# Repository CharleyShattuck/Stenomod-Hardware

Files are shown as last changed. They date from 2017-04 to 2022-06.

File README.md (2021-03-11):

# Stenomod-Hardware

TinyMod4 is the current keyboard. TinyModsplit is a prototype split version of TinyMod.

formerly:
In addition to the left hand module for stenomod15, the one with the split S- into two keys, we now have the three boards currently being used in stenomods. Stenomod16 is the new hinge model. Tiny-stenomod is the new TinyMod model.

KiCad footprints used here were found at https://github.com/ruiqimao/keyboard-pcb-guide

License for Gateron.pretty is not known as it was modified from the file "CHERRY\_PCB\_100H.kicad\_mod", obtained at  https://github.com/stormbard/Keyboard.pretty  which had no expressed license.

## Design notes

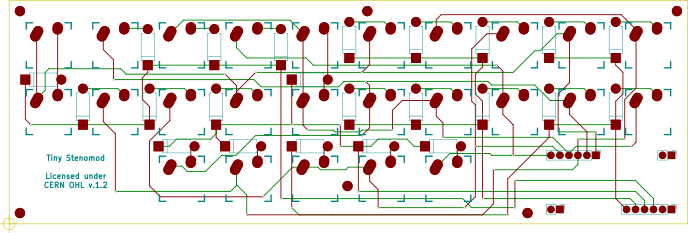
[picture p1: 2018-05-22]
Tiny-stenomod/Tiny-stenomod-brd.png

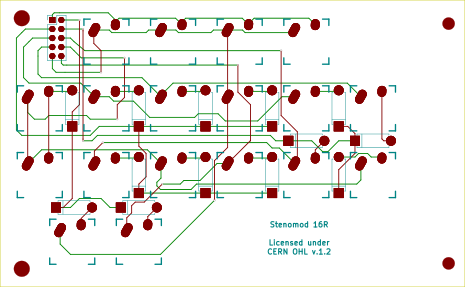
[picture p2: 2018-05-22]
Stenomod/Stenomod_Right/stenomod-16R-brd.png

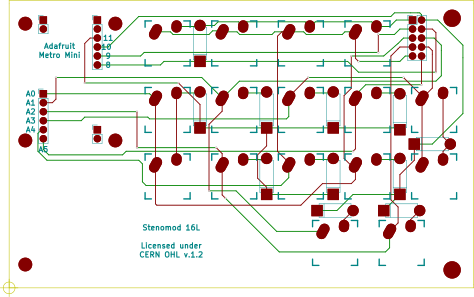
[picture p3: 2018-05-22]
Stenomod/Stenomod_Left/stenomod-16L-brd.png

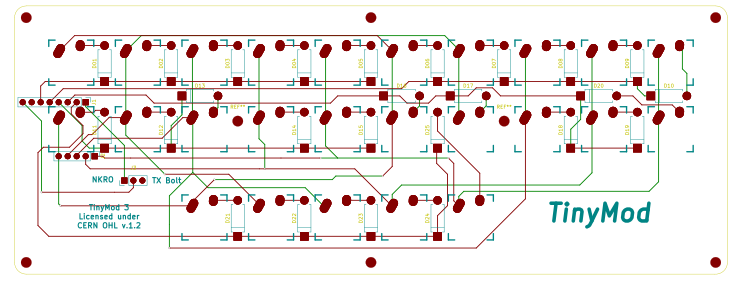
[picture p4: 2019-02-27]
TinyMod/TinyMod3/TinyMod3-brd.png

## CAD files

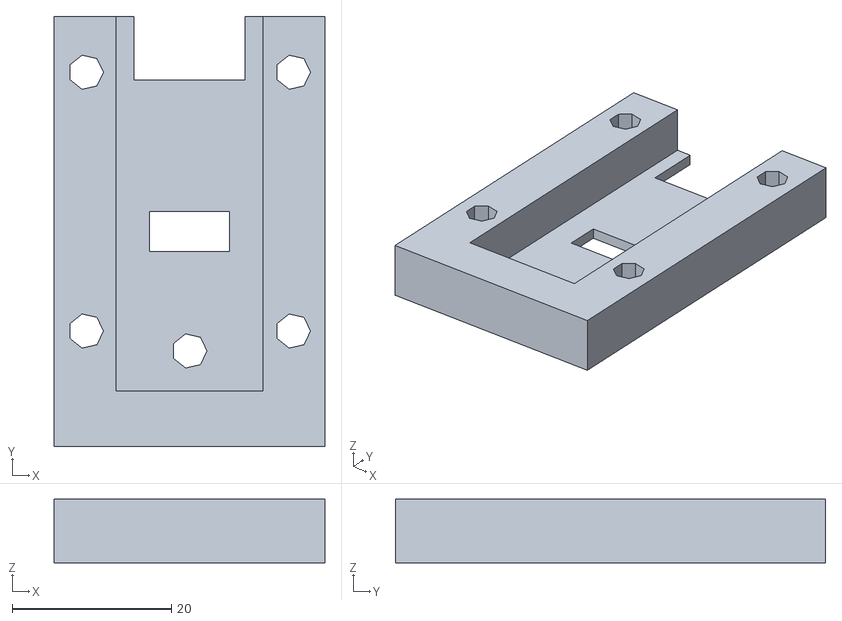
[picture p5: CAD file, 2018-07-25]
Stenomod/Stenomod_Hinge/stenomod-hinge.stl
34.0 x 54.0 x 8.00

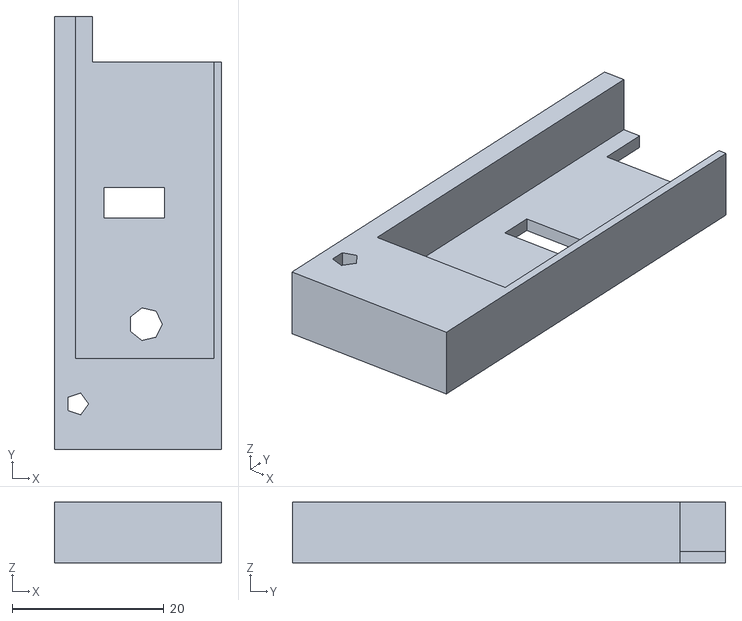
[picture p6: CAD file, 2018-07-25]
TinyMod/TinyModCover/TinyMod.stl
22.0 x 57.0 x 8.00

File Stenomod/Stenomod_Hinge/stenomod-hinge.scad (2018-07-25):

module base(){
    translate([-17, -27, 0]){
        cube([34, 54, 8]);
    }
};

module window(){
    translate([-5, -2.5, 0]){
        cube([10, 5, 10]);
    }
};

module notch(){
    translate([-7, 19, 0]){
        cube([14, 8, 10]);
    }
};

module hole(){
    cylinder(10, 2.2, 2.2, 0);
};

module reset(){
    translate([0, -15, 0]){
        hole();
    }
};

module screws(){
    translate([-13, 20, 0]){
        hole();
    }
    translate([13, 20, 0]){
        hole();
    }
    translate([-13, -12.5, 0]){
        hole();
    }
    translate([13, -12.5, 0]){
        hole();
    }
};

module middle(){
    translate([-9.25, -20, 1.5]){
        cube([18.5, 48, 10]);
    }
};

module top(){
    difference(){
        base();
        window();
        notch();
        reset();
        screws();
        middle();
    }
}

top();

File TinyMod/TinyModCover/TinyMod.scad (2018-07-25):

module base(){
    translate([-12, -27, 0]){
        cube([21, 57, 8]);
    }
};

module window(){
    translate([-5.5, 3.5, 0]){
        cube([8, 4, 10]);
    }
};

module notch(){
    translate([-7, 24, 0]){
        cube([16, 8, 10]);
    }
};

module hole1(){
    translate([0, 5, 0]){
        cylinder(10, 2.2, 2.2, 0);
    }
};

module hole2(){
    translate([0, 5, 0]){
        cylinder(10, 1.5, 1.5, 0);
    }
};

module reset(){
    translate([0, -15.5, 0]){
        hole1();
    }
};

module screws(){
    translate([-9, -26, 0]){
        hole2();
    }
};

module middle(){
    translate([-9.25, -15, 1.5]){
        cube([18.5, 48, 10]);
    }
};

module lip(){
    translate([9, -27, 0]){
        cube([1, 51, 8]);
    }
}

module top(){
    lip();
    difference(){
        base();
        window();
        notch();
        reset();
        screws();
        middle();
    }
}

top();

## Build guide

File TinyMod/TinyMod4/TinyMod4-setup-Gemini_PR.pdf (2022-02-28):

# TinyMod

You should find these two items in the box. A TinyMod keyboard and a microUSB cable.

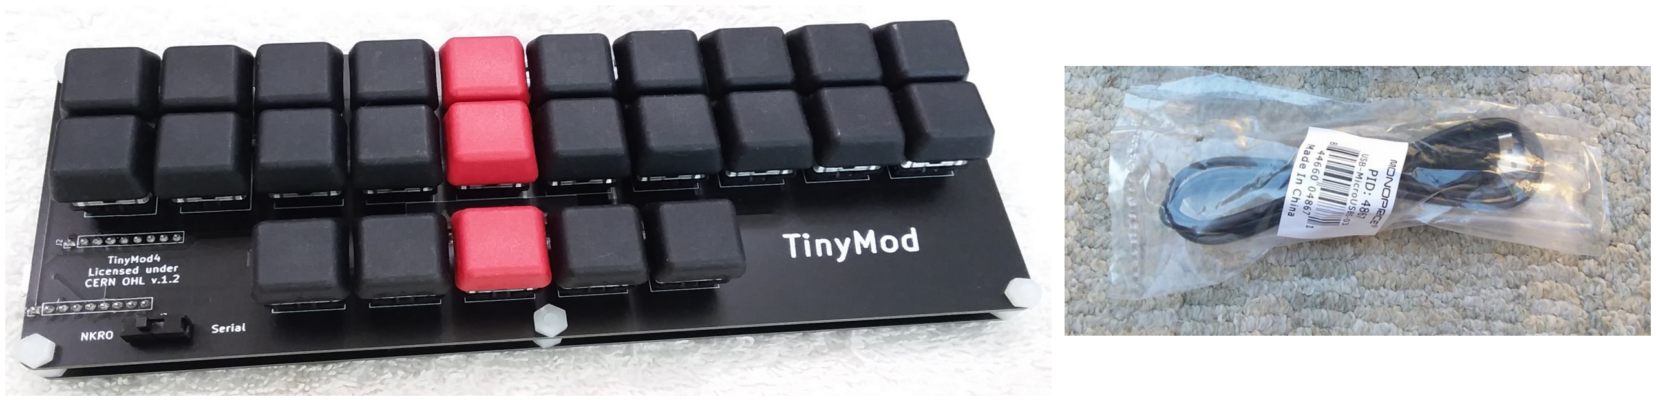
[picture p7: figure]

It’s easy to set up your TinyMod. Just plug the USB cable into the socket on the left hand side of the keyboard and plug the other end into your computer. If you’re using NKRO keyboard protocol no driver should be needed, but if you’re using Gemini PR serial protocol and a question of drivers comes up you will need to get the SiLabs driver from:

http://www.silabs.com/products/development-tools/software/usb-to-uart-bridge-vcp-drivers

You will want to install Plover if you haven’t already: http://www.openstenoproject.org/plover Version 4 is highly recommended!

If you’re running Linux you’ll need to get serial permissions. For Ubuntu use the following at the command-line: sudo usermod -a -G dialout “$USER”

The slider switch as pictured here is set to tell the TinyMod to use NKRO
protocol at power up. If you slide the switch to the right position and
restart the keyboard by unplugging it and plugging it back in then
Gemini PR serial protocol will be used. If this picture is not clear enough, just look at your actual keyboard in the lower left corner. You should see the switch and its labels. The default when shipped should be NKRO keyboard protocol.

In order to use keyboard protocol with Plover you should choose it from the “machine” pull-down menu on the main screen of Plover. Press the “connected” button if needed to get Plover in sync with TinyMod.

If you’re instead using Gemini PR serial protocol, click the “configure” button, choose “machine”, “Gemini PR”, then “scan”. Choose the COM or serial port corresponding to your keyboard from the drop down menu. You probably don’t need to change anything else. It’s 9600, 8, 1, N, and the time out doesn’t seem to matter. No flow control. Now click “OK”.

The settings may not be saved until you close Plover, so be sure to exit the program before turning your computer off. Just closing the window is not enough. You should be able to start writing with your TinyMod now.

Thanks for your order!

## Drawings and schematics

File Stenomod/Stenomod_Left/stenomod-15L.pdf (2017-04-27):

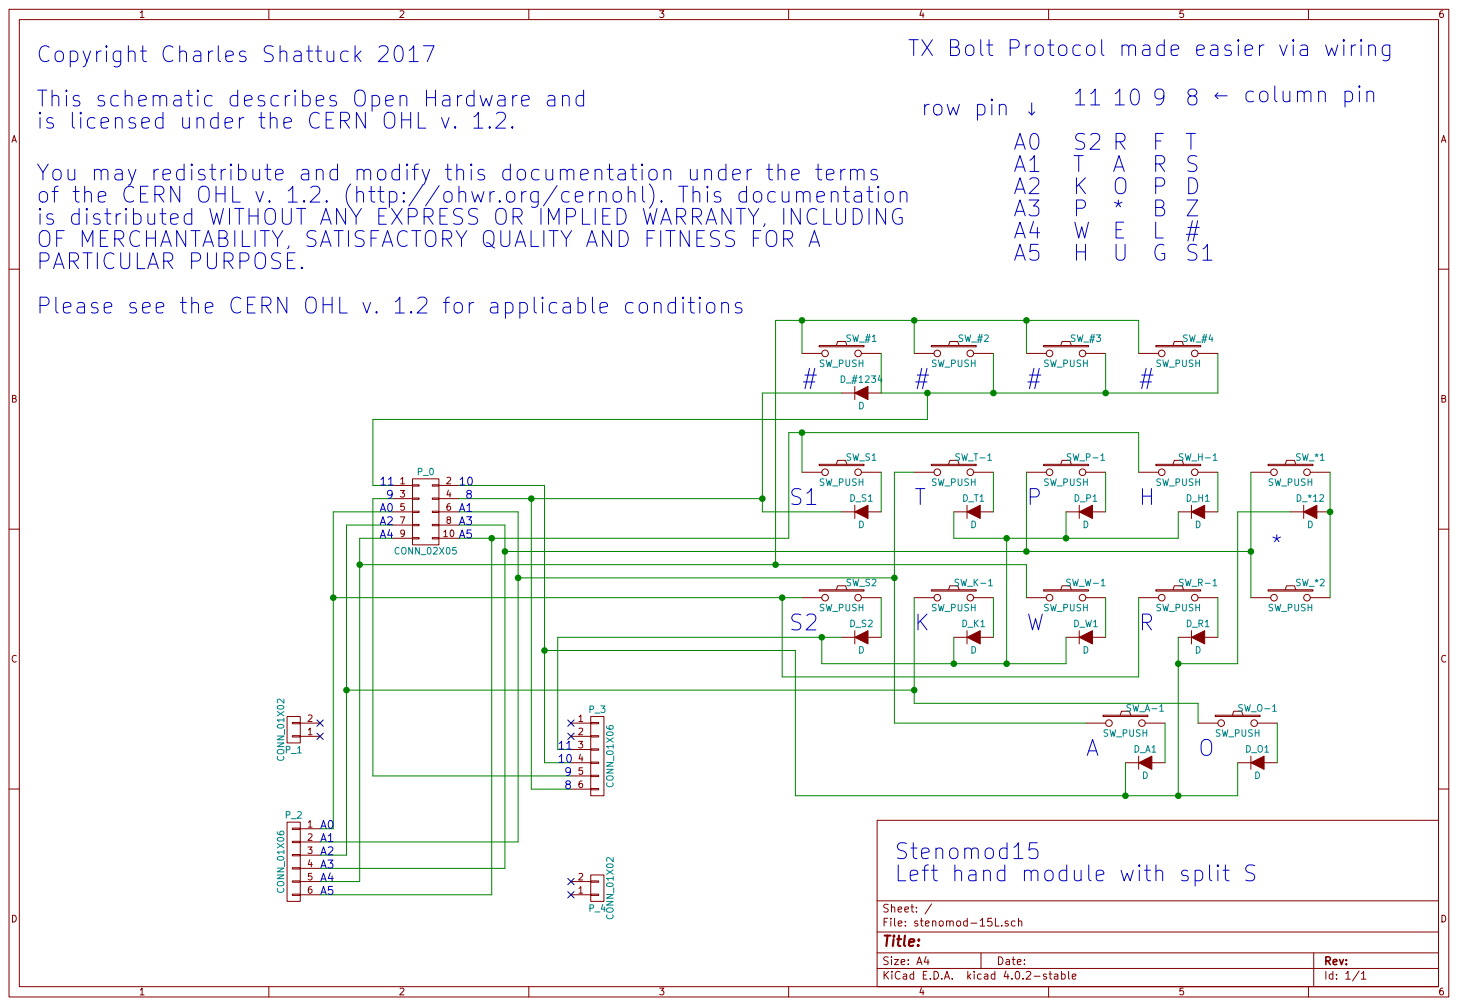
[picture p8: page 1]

TX Bolt Protocol made easier via wiring
column pin row pin

D_O1 D Copyright Charles Shattuck 2017
This schematic describes Open Hardware and
is licensed under the CERN OHL v. 1.2.

You may redistribute and modify this documentation under the terms
of the CERN OHL v. 1.2. (http://ohwr.org/cernohl). This documentation
is distributed WITHOUT ANY EXPRESS OR IMPLIED WARRANTY, INCLUDING
OF MERCHANTABILITY, SATISFACTORY QUALITY AND FITNESS FOR A
PARTICULAR PURPOSE.
Please see the CERN OHL v. 1.2 for applicable conditions

A1 A2 A3 A4 A5 | 10 A0 | SW_K-1 SW_PUSH

SW_S2 SW_PUSH
S2

Stenomod15
Left hand module with split S

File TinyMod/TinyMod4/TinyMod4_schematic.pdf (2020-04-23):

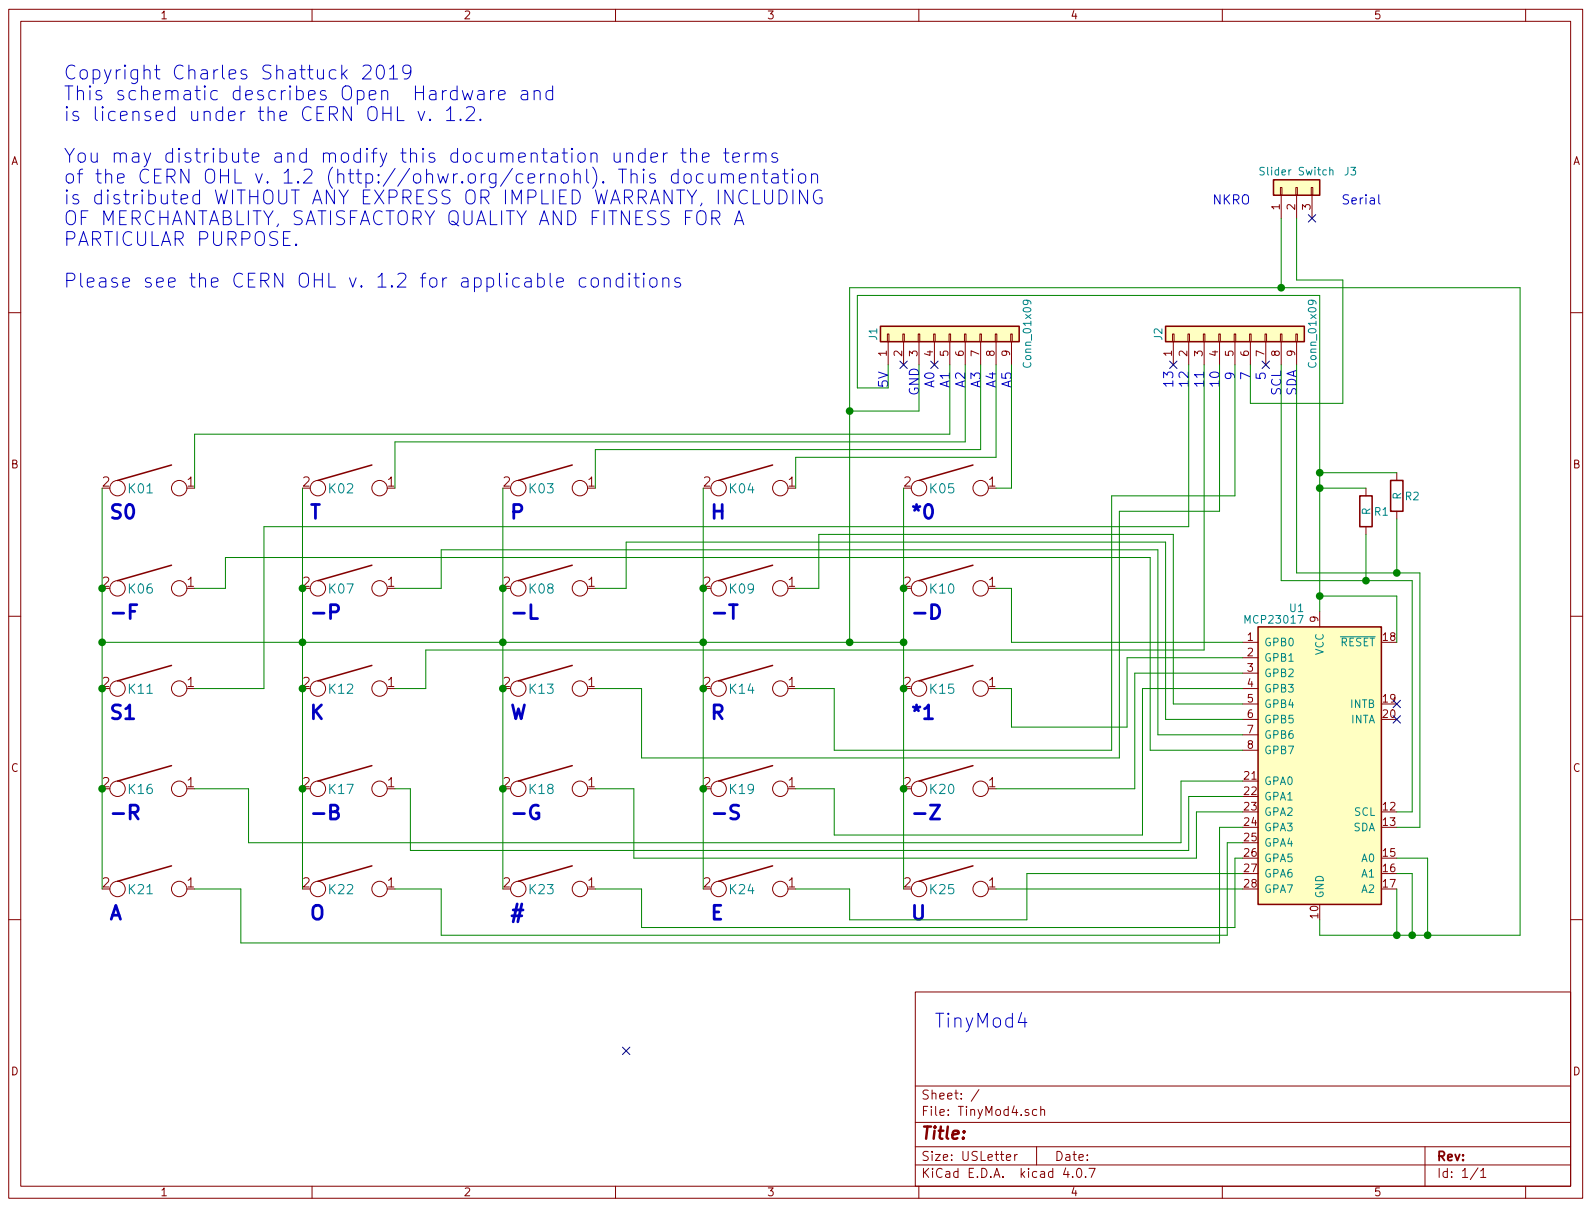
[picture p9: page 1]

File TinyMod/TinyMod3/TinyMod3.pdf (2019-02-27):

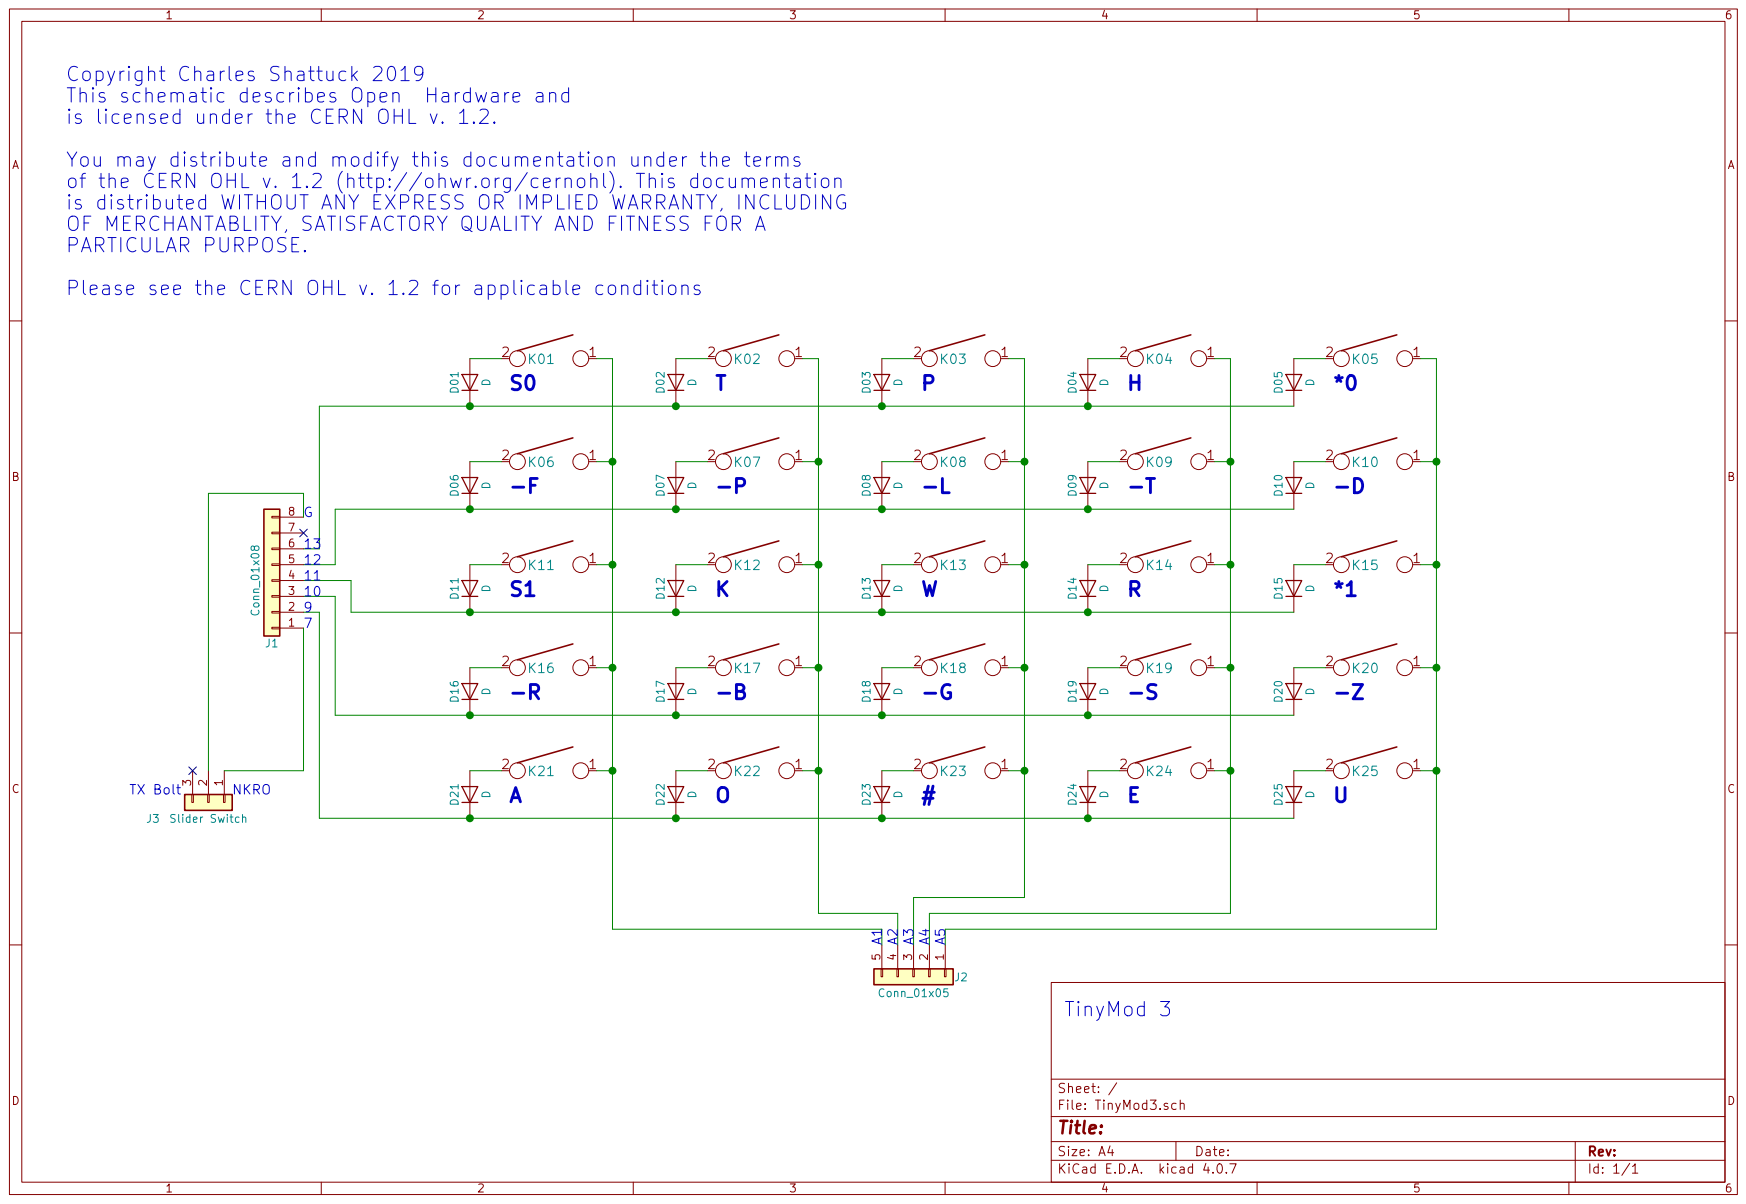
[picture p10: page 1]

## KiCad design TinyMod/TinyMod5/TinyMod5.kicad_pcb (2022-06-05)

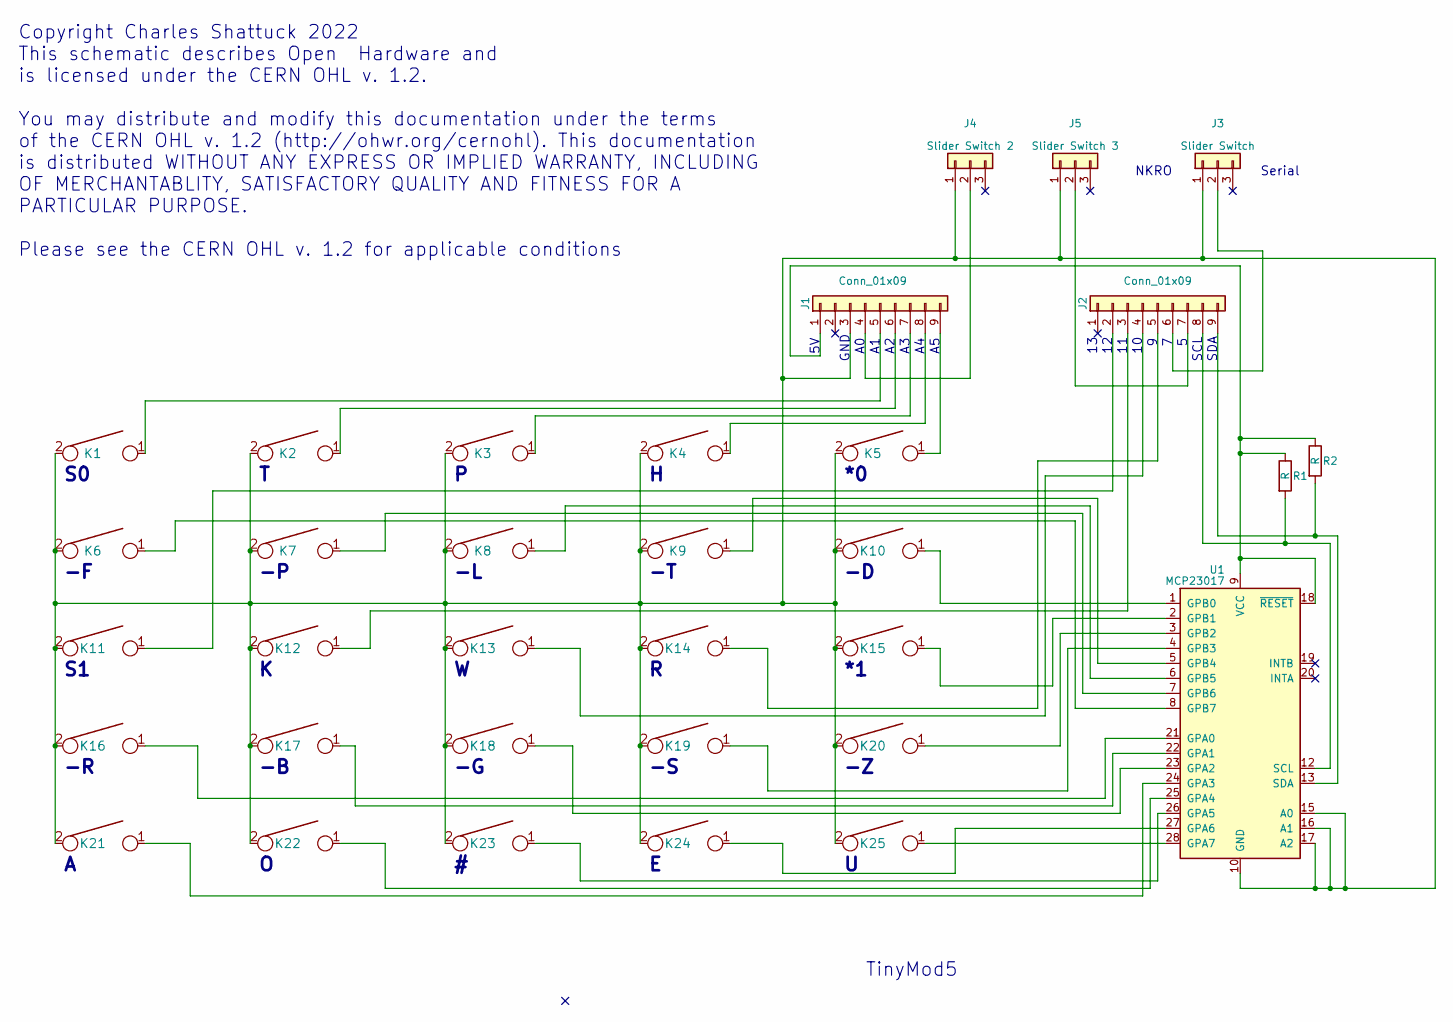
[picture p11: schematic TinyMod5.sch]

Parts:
J1, J2: Conn_01x09; Pin_Header_Straight_1x09_Pitch2.54mm
J3: Slider Switch; Pin_Header_Straight_1x03_Pitch2.54mm
J4: Slider Switch 2; Pin_Header_Straight_1x03_Pitch2.54mm
J5: Slider Switch 3; Pin_Header_Straight_1x03_Pitch2.54mm
K1, K2, K3, K4, K5, K6, K7, K8, K9, K10, K11, K12, K13, K14, K15, K16, K17, K18, K19, K20, K21, K22, K23, K24, K25: KEYSW; SW_Cherry_MX1A_1.00u_PCB
R1, R2: R; R_Axial_DIN0411_L9.9mm_D3.6mm_P15.24mm_Horizontal
U1: MCP23017; DIP-28_W7.62mm_Socket_LongPads

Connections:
unnamed: J1.1, R1.1, R2.1, U1.9 (VCC), U1.18 (~RESET)
unnamed: J1.3, J3.1, J4.1, J5.1, K1.2, K2.2, K3.2, K4.2, K5.2, K6.2, K7.2, K8.2, K9.2, K10.2, K11.2, K12.2, K13.2, K14.2, K15.2, K16.2, K17.2, K18.2, K19.2, K20.2, K21.2, K22.2, K23.2, K24.2, K25.2, U1.10 (GND), U1.15 (A0), U1.16 (A1), U1.17 (A2)
unnamed: J1.4, J4.2
unnamed: J1.5, K1.1
unnamed: J1.6, K2.1
unnamed: J1.7, K3.1
unnamed: J1.8, K4.1
unnamed: J1.9, K5.1
unnamed: J2.2, K11.1
unnamed: J2.3, K12.1
unnamed: J2.4, K13.1
unnamed: J2.5, K14.1
unnamed: J2.6, J3.2
unnamed: J2.7, J5.2
unnamed: J2.8, R1.2, U1.12 (SCL)
unnamed: J2.9, R2.2, U1.13 (SDA)
unnamed: K6.1, U1.8 (GPB7)
unnamed: K7.1, U1.7 (GPB6)
unnamed: K8.1, U1.6 (GPB5)
unnamed: K9.1, U1.5 (GPB4)
unnamed: K10.1, U1.1 (GPB0)
unnamed: K15.1, U1.2 (GPB1)
unnamed: K16.1, U1.21 (GPA0)
unnamed: K17.1, U1.22 (GPA1)
unnamed: K18.1, U1.23 (GPA2)
unnamed: K19.1, U1.4 (GPB3)
unnamed: K20.1, U1.3 (GPB2)
unnamed: K21.1, U1.24 (GPA3)
unnamed: K22.1, U1.25 (GPA4)
unnamed: K23.1, U1.26 (GPA5)
unnamed: K24.1, U1.27 (GPA6)
unnamed: K25.1, U1.28 (GPA7)

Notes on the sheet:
NKRO
Serial
TinyMod5
Copyright Charles Shattuck 2022 This schematic describes Open Hardware and is licensed under the CERN OHL v. 1.2. You may distribute and modify this documentation under the terms of the CERN OHL v. 1.2 (http://ohwr.org/cernohl). This documentation is distributed WITHOUT ANY EXPRESS OR IMPLIED WARRA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
GND
SDA
SCL

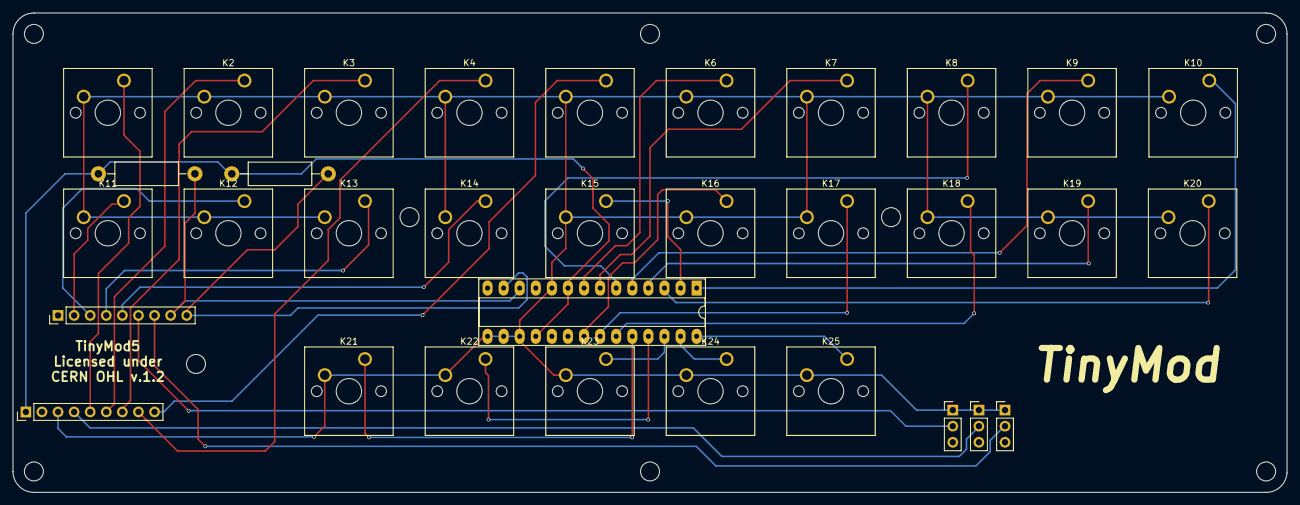
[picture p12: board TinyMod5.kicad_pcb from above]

Board: 2 copper layers, 201.2 x 75.7 mm, 33 parts (0 on the bottom side), 32 nets.

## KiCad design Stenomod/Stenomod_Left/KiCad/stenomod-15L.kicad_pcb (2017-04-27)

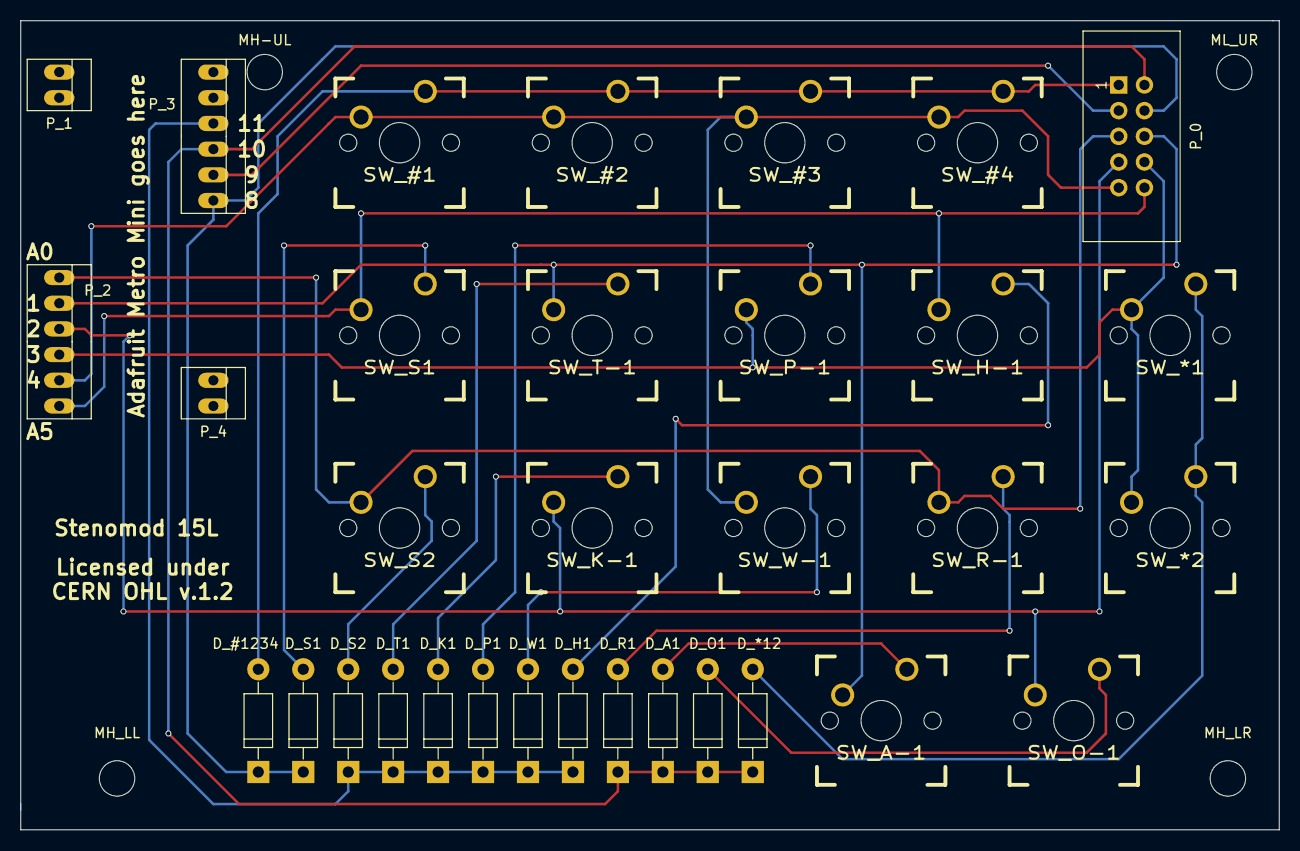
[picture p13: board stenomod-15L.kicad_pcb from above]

Board: 2 copper layers, 124.5 x 80.0 mm, 37 parts (0 on the bottom side), 22 nets.

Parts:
D_#1234: D; D_DO-41_SOD81_P10.16mm_Horizontal
D_*12: D; D_DO-41_SOD81_P10.16mm_Horizontal
D_A1: D; D_DO-41_SOD81_P10.16mm_Horizontal
D_H1: D; D_DO-41_SOD81_P10.16mm_Horizontal
D_K1: D; D_DO-41_SOD81_P10.16mm_Horizontal
D_O1: D; D_DO-41_SOD81_P10.16mm_Horizontal
D_P1: D; D_DO-41_SOD81_P10.16mm_Horizontal
D_R1: D; D_DO-41_SOD81_P10.16mm_Horizontal
D_S1, D_S2: D; D_DO-41_SOD81_P10.16mm_Horizontal
D_T1: D; D_DO-41_SOD81_P10.16mm_Horizontal
D_W1: D; D_DO-41_SOD81_P10.16mm_Horizontal
MH-UL: MH_3.5mm; MountingHole_3.5mm
MH_LL: MH_3.5mm; MountingHole_3.5mm
MH_LR: MH_3.5mm; MountingHole_3.5mm
ML_UR: MH_3.5mm; MountingHole_3.5mm
P_0: CONN_02X05; IDC_Header_Straight_10pins
P_1, P_4: CONN_01X02; PINHEAD1-2
P_2, P_3: CONN_01X06; PINHEAD1-6
SW_#1, SW_#2, SW_#3, SW_#4: SW_PUSH; Gateron
SW_*1, SW_*2: SW_PUSH; Gateron
SW_A-1: SW_PUSH; Gateron
SW_H-1: SW_PUSH; Gateron
SW_K-1: SW_PUSH; Gateron
SW_O-1: SW_PUSH; Gateron
SW_P-1: SW_PUSH; Gateron
SW_R-1: SW_PUSH; Gateron
SW_S1, SW_S2: SW_PUSH; Gateron
SW_T-1: SW_PUSH; Gateron
SW_W-1: SW_PUSH; Gateron

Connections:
unnamed: D_#1234.1, D_S1.1, P_0.4, P_3.6
unnamed: D_#1234.2, P_0.1, SW_#1.2, SW_#2.2, SW_#3.2, SW_#4.2
unnamed: D_*12.1, D_A1.1, D_O1.1, D_R1.1, P_0.2, P_3.4
unnamed: D_*12.2, SW_*1.2, SW_*2.2
unnamed: D_A1.2, SW_A-1.2
unnamed: D_H1.1, D_K1.1, D_P1.1, D_S2.1, D_T1.1, D_W1.1, P_3.3
unnamed: D_H1.2, SW_H-1.2
unnamed: D_K1.2, SW_K-1.2
unnamed: D_O1.2, SW_O-1.2
unnamed: D_P1.2, SW_P-1.2
unnamed: D_R1.2, SW_R-1.2
unnamed: D_S1.2, SW_S1.2
unnamed: D_S2.2, SW_S2.2
unnamed: D_T1.2, SW_T-1.2
unnamed: D_W1.2, SW_W-1.2
unnamed: P_0.3, P_3.5
unnamed: P_0.5, P_2.1, SW_R-1.1, SW_S2.1
unnamed: P_0.6, P_2.2, SW_A-1.1, SW_T-1.1
unnamed: P_0.7, P_2.3, SW_K-1.1, SW_O-1.1
unnamed: P_0.8, P_2.4, SW_*1.1, SW_*2.1, SW_P-1.1
unnamed: P_0.9, P_2.5, SW_#1.1, SW_#2.1, SW_#3.1, SW_#4.1, SW_W-1.1
unnamed: P_0.10, P_2.6, SW_H-1.1, SW_S1.1

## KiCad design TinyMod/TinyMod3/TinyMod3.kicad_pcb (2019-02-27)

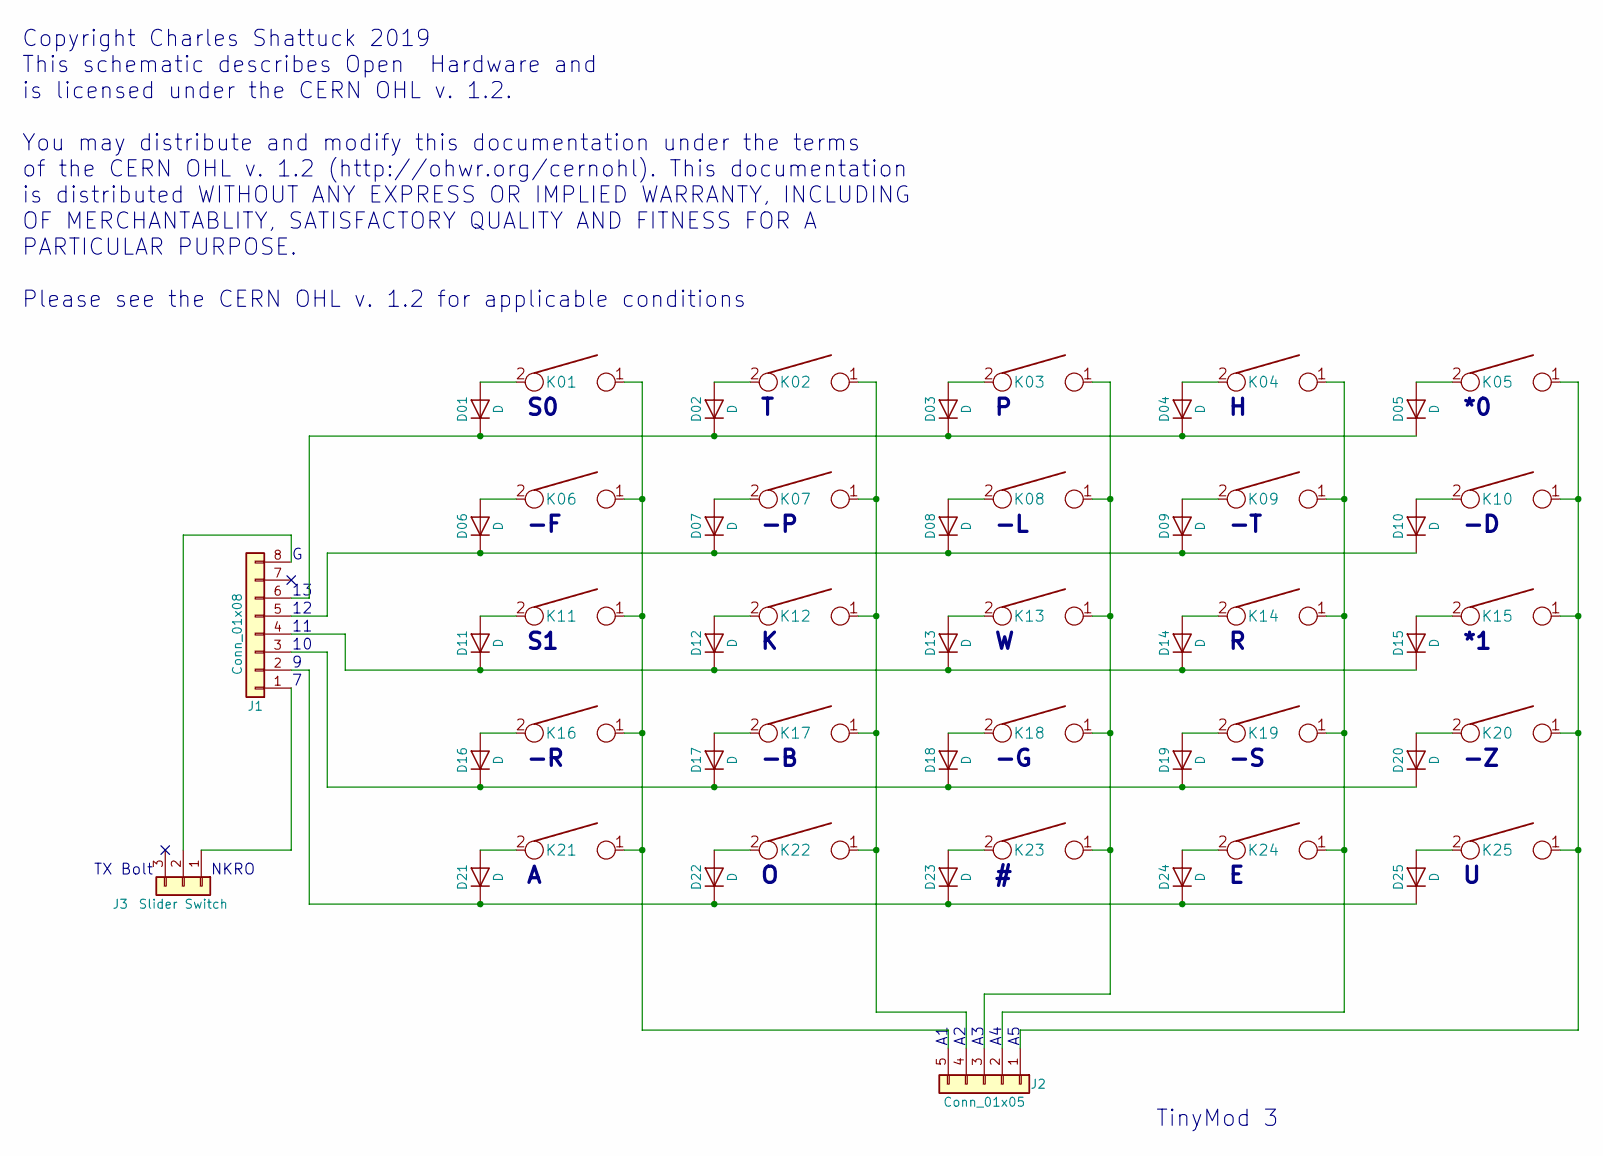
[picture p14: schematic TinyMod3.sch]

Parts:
D01, D02, D03, D04, D05, D06, D07, D08, D09, D10, D11, D12, D13, D14, D15, D16, D17, D18, D19, D20, D21, D22, D23, D24, D25: D; D_DO-15_P10.16mm_Horizontal
J1: Conn_01x08; Pin_Header_Straight_1x08_Pitch2.54mm
J2: Conn_01x05; Pin_Header_Straight_1x05_Pitch2.54mm
J3: Slider Switch; Pin_Header_Straight_1x03_Pitch2.54mm
K01, K02, K03, K04, K05, K06, K07, K08, K09, K10, K11, K12, K13, K14, K15, K16, K17, K18, K19, K20, K21, K22, K23, K24, K25: KEYSW; Mx_Alps_100

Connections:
unnamed: D01.1 (K), D02.1 (K), D03.1 (K), D04.1 (K), D05.1 (K), J1.6
unnamed: D01.2 (A), K01.2
unnamed: D02.2 (A), K02.2
unnamed: D03.2 (A), K03.2
unnamed: D04.2 (A), K04.2
unnamed: D05.2 (A), K05.2
unnamed: D06.1 (K), D07.1 (K), D08.1 (K), D09.1 (K), D10.1 (K), J1.5
unnamed: D06.2 (A), K06.2
unnamed: D07.2 (A), K07.2
unnamed: D08.2 (A), K08.2
unnamed: D09.2 (A), K09.2
unnamed: D10.2 (A), K10.2
unnamed: D11.1 (K), D12.1 (K), D13.1 (K), D14.1 (K), D15.1 (K), J1.4
unnamed: D11.2 (A), K11.2
unnamed: D12.2 (A), K12.2
unnamed: D13.2 (A), K13.2
unnamed: D14.2 (A), K14.2
unnamed: D15.2 (A), K15.2
unnamed: D16.1 (K), D17.1 (K), D18.1 (K), D19.1 (K), D20.1 (K), J1.3
unnamed: D16.2 (A), K16.2
unnamed: D17.2 (A), K17.2
unnamed: D18.2 (A), K18.2
unnamed: D19.2 (A), K19.2
unnamed: D20.2 (A), K20.2
unnamed: D21.1 (K), D22.1 (K), D23.1 (K), D24.1 (K), D25.1 (K), J1.2
unnamed: D21.2 (A), K21.2
unnamed: D22.2 (A), K22.2
unnamed: D23.2 (A), K23.2
unnamed: D24.2 (A), K24.2
unnamed: D25.2 (A), K25.2
unnamed: J1.1, J3.1
unnamed: J1.8, J3.2
unnamed: J2.1, K05.1, K10.1, K15.1, K20.1, K25.1
unnamed: J2.2, K04.1, K09.1, K14.1, K19.1, K24.1
unnamed: J2.3, K03.1, K08.1, K13.1, K18.1, K23.1
unnamed: J2.4, K02.1, K07.1, K12.1, K17.1, K22.1
unnamed: J2.5, K01.1, K06.1, K11.1, K16.1, K21.1

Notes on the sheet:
NKRO
TX Bolt
TinyMod 3
Copyright Charles Shattuck 2019 This schematic describes Open Hardware and is licensed under the CERN OHL v. 1.2. You may distribute and modify this documentation under the terms of the CERN OHL v. 1.2 (http://ohwr.org/cernohl). This documentation is distributed WITHOUT ANY EXPRESS OR IMPLIED WARRA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

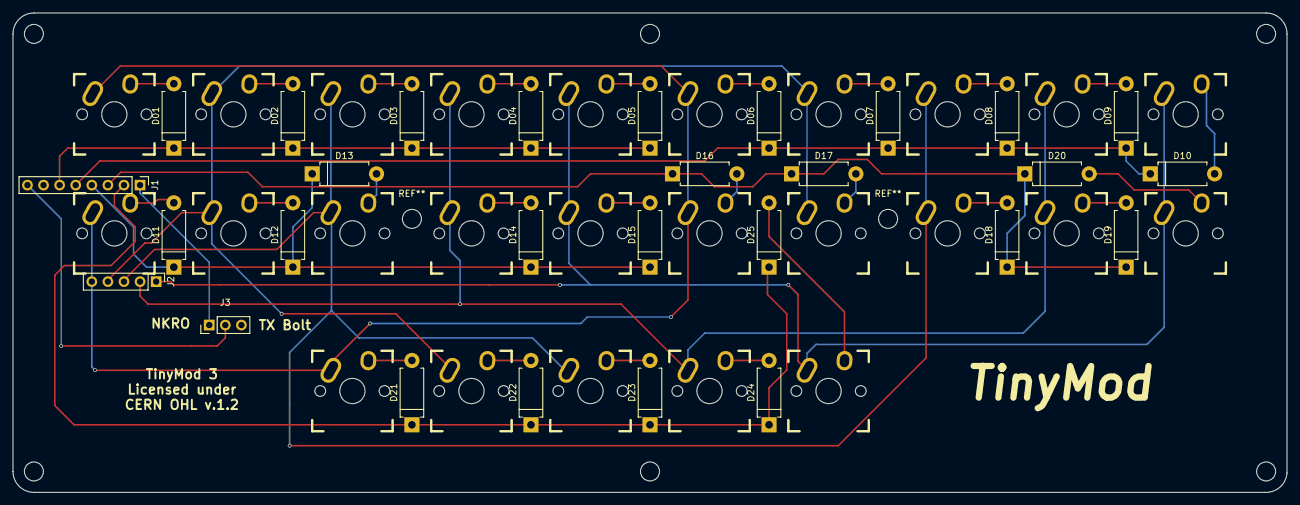
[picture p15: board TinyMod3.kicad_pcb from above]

Board: 2 copper layers, 201.2 x 75.7 mm, 53 parts (0 on the bottom side), 37 nets.

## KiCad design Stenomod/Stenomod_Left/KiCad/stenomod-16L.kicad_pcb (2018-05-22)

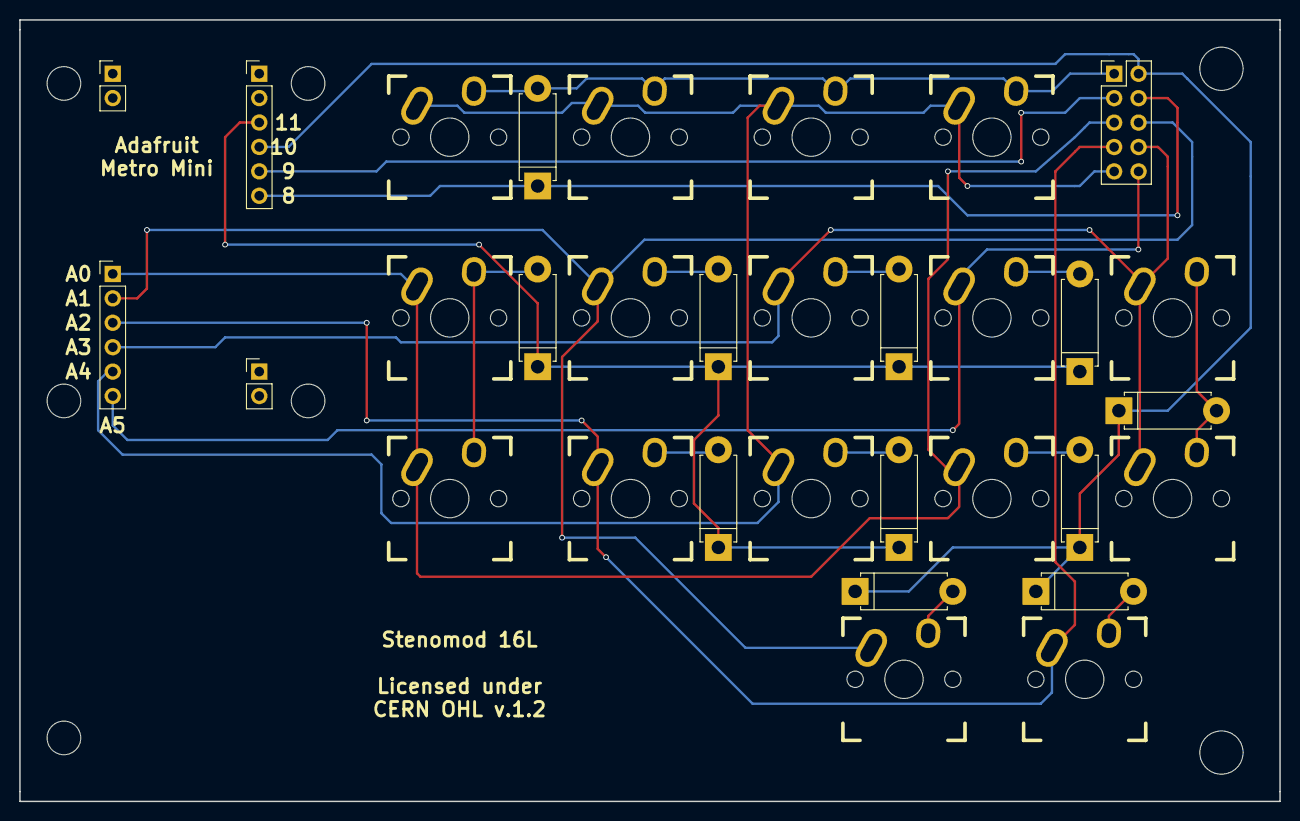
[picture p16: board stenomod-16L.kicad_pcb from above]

Board: 2 copper layers, 131.1 x 81.3 mm, 30 parts (0 on the bottom side), 21 nets.

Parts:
D1, D2, D3, D4, D5, D6, D7, D8, D9, D10, D11: D; D_5W_P10.16mm_Horizontal
J1, J2: Conn_01x06; Pin_Header_Straight_1x06_Pitch2.54mm
J_10: Conn_02x05_Odd_Even; Pin_Header_Straight_2x05_Pitch2.54mm
K1, K2, K3, K4, K5, K6, K7, K8, K9, K10, K11, K12, K13, K14, K15, K16: KEYSW; Mx_Alps_100

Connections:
unnamed: D1.1, J1.6, J_10.4
unnamed: D1.2, J_10.1, K1.2, K14.2, K15.2, K16.2
unnamed: D2.1, D3.1, D4.1, D5.1, D8.1, D9.1, J1.3
unnamed: D2.2, K2.2
unnamed: D3.2, K3.2
unnamed: D4.2, K4.2
unnamed: D5.2, K5.2, K12.2
unnamed: D6.2, K6.2, K13.2
unnamed: D7.2, K7.2
unnamed: D8.2, K8.2
unnamed: D9.2, K9.2
unnamed: D6.1, D7.1, D10.1, D11.1, J1.4, J_10.2
unnamed: D10.2, K10.2
unnamed: D11.2, K11.2
unnamed: J1.5, J_10.3
unnamed: J2.1, J_10.5, K5.1, K7.1, K12.1
unnamed: J2.2, J_10.6, K4.1, K11.1
unnamed: J2.3, J_10.7, K9.1, K10.1
unnamed: J2.4, J_10.8, K3.1, K6.1, K13.1
unnamed: J2.5, J_10.9, K1.1, K8.1, K14.1, K15.1, K16.1
unnamed: J2.6, J_10.10, K2.1

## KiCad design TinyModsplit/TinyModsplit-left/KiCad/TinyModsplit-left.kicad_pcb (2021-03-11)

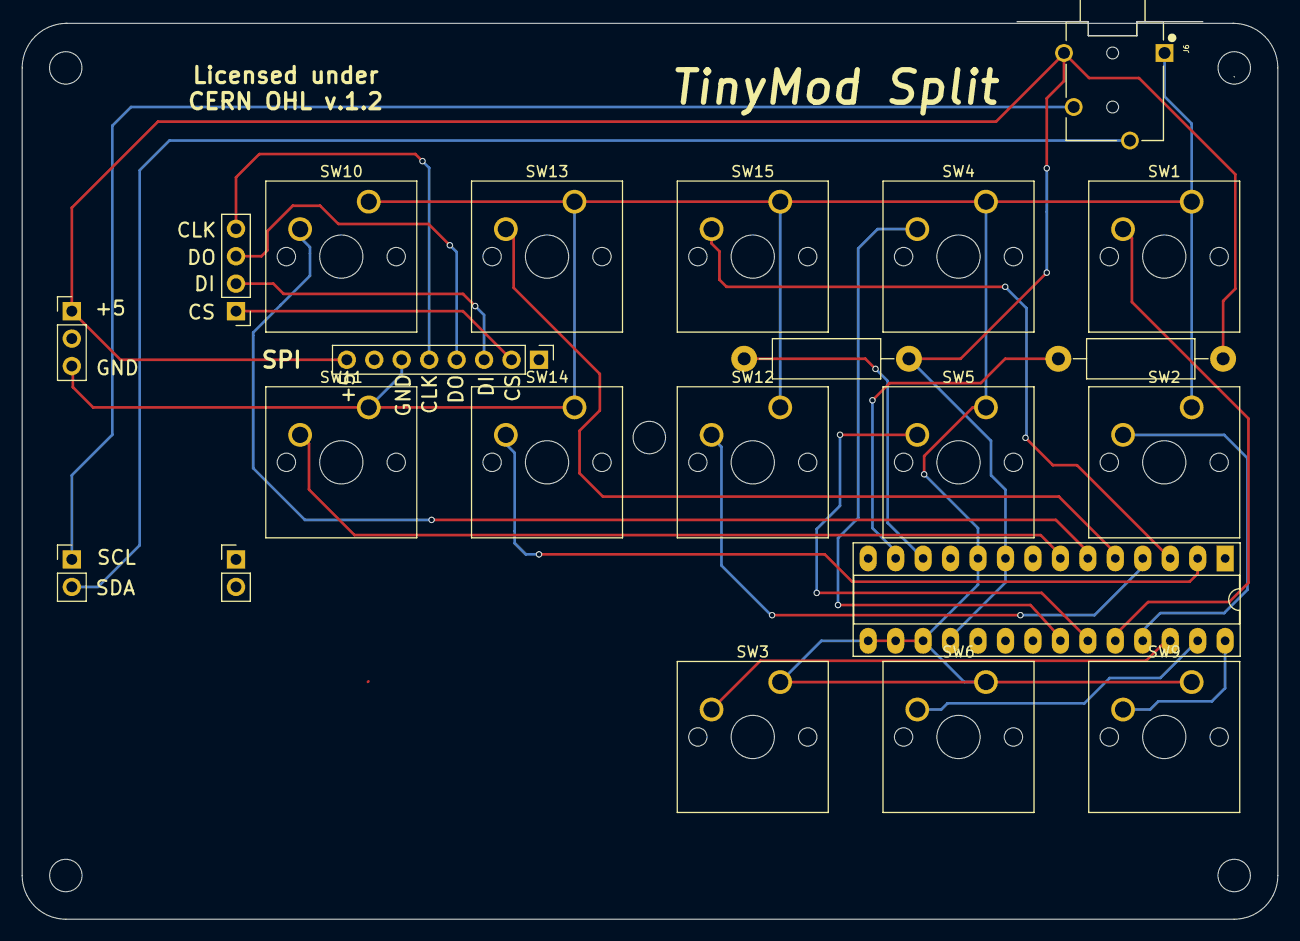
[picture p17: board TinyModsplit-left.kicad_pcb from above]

Board: 2 copper layers, 116.2 x 82.9 mm, 22 parts (0 on the bottom side), 23 nets.

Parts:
J1: Conn_01x03; Pin_Header_Straight_1x03_Pitch2.54mm
J2, J5: Conn_01x02; Pin_Header_Straight_1x02_Pitch2.54mm
J3: Conn_01x08; Pin_Header_Straight_1x08_Pitch2.54mm
J6: SJ-43514; CUI_SJ-43514
J7: Conn_01x04; Pin_Header_Straight_1x04_Pitch2.54mm
R1, R2: R; R_Axial_DIN0411_L9.9mm_D3.6mm_P15.24mm_Horizontal
SW1, SW2, SW3, SW4, SW5, SW6, SW9, SW10, SW11, SW12, SW13, SW14, SW15: SW_DIP_x01; SW_Cherry_MX1A_1.00u_PCB
U1: MCP23017; DIP-28_W7.62mm_Socket_LongPads

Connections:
unnamed: J1.1, J3.8, J6.4, R1.1, R2.1, U1.9, U1.18
unnamed: J1.3, J3.6, J6.1, SW1.1, SW2.1, SW3.1, SW4.1, SW5.1, SW6.1, SW9.1, SW10.1, SW11.1, SW12.1, SW13.1, SW14.1, SW15.1, U1.10, U1.15, U1.16, U1.17
unnamed: J2.1, J6.2
unnamed: J2.2, J6.3
unnamed: J3.2, J7.1
unnamed: J3.3, J7.2
unnamed: J3.4, J7.3
unnamed: J3.5, J7.4
unnamed: R1.2, U1.12
unnamed: R2.2, U1.13
unnamed: SW1.2, U1.24
unnamed: SW2.2, U1.25
unnamed: SW3.2, U1.26
unnamed: SW4.2, U1.22
unnamed: SW5.2, U1.23
unnamed: SW6.2, U1.27
unnamed: SW9.2, U1.28
unnamed: SW10.2, U1.6
unnamed: SW11.2, U1.7
unnamed: SW12.2, U1.4
unnamed: SW13.2, U1.5
unnamed: SW14.2, U1.2
unnamed: SW15.2, U1.3

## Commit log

2017-04-26 schematic and PCB
    [stenomod-15L.kicad_pcb, stenomod-15L.sch]
2017-04-26 Gateron footprint
2017-04-27 more text on the board
    [stenomod-15L.kicad_pcb]
2018-05-22 stenomod Open Source hardware as of May 22, 2018
    [Tiny-stenomod.kicad_pcb, Tiny-stenomod.sch, stenomod-16L.kicad_pcb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]
2018-07-25 Added 3D printed covers for the Arduinos
    [TinyMod.scad, TinyMod.stl, stenomod-hinge.scad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]
2019-02-27 Added TinyMod 3 cad files
    [TinyMod3.kicad_pcb, TinyMod3.sch]
2019-08-28 TinyMod4 PCB
    [TinyMod4.kicad_pcb, TinyMod4.sch]
2020-04-23 TinyMod4 schematic PDF
2021-03-11 TinyModsplit first prototype
    [TinyModsplit-left-B.Cu.gbr, TinyModsplit-left-B.Mask.gbr, TinyModsplit-left-Edge.Cuts.gbr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]
2021-03-19 Fixed wiring errors, changed outline
2021-07-03 All the TinyMod4 Gerbers in one zip file.
    The way JLCPCB likes it.
2021-07-10 Sorted repo folders into keyboards and subfolders for KiCad and Gerber
    [Tiny-stenomod.kicad_pcb, Tiny-stenomod.sch, TinyMod.scad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]
2022-06-05 TinyMod5 CAD files
    TinyMod5.zip is the Gerber files, as sent to JLCPCB
    [TinyMod5-B.Cu.gbr, TinyMod5-B.Mask.gbr, TinyMod5-Edge.Cuts.gbr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]

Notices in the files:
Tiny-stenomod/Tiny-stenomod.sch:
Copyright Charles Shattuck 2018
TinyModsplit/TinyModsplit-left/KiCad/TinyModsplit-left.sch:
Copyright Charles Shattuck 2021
